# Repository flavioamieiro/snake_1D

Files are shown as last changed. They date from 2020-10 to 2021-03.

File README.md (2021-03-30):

A snake trapped in one dimension.

It's always there, but you'll need a strip of ws2812b LEDs to see and interact with it.

Here, you'll find two species: The [python](fadecandy_python/#readme),
for which you'll need a computer and a
[fadecandy](https://github.com/scanlime/fadecandy) and the
[tiny](attiny85_arduino_IDE/#readme), for which you can use the
standalone [hardware](hardware/#readme).

The software in this repository is licensed under the GPLv3 and the hardware
under the CERN-OHL-S v2.

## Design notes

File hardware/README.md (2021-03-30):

Kicad project with schematics and PCB design for the 1D Snake Game
running on an ATTiny85.

This source describes Open Hardware and is licensed under the
CERN-OHL-S v2.  You may redistribute and modify this source and make
products using it under the terms of the CERN-OHL-S v2
(https://ohwr.org/cern_ohl_s_v2.txt).

This source is distributed WITHOUT ANY EXPRESS OR IMPLIED WARRANTY,
INCLUDING OF MERCHANTABILITY, SATISFACTORY QUALITY AND FITNESS FOR A
PARTICULAR PURPOSE. Please see the CERN-OHL-S v2 for applicable
conditions.

Source location:
https://github.com/flavioamieiro/snake_1D

As per CERN-OHL-S v2 section 4, should You produce hardware based on
this source, You must where practicable maintain the Source Location
visible on the external case of the Gizmo or other products you make
using this source.

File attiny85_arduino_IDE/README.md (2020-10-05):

Code to run the 1D Snake Game in an ATtiny85 microcrontroler.

It was written in the arduino IDE using
[ATTinyCore](https://github.com/SpenceKonde/ATTinyCore). Please refer
to [their
documentation](https://github.com/SpenceKonde/ATTinyCore#readme) for
installation/programming instructions.

You can refer to the [hardware design files](../hardware/) to see what
you need to hookup to the microcrontroler. If you only want to test it
out, you might get away with only 5V between `Vcc` and `GND`, the
pushbutton on `PB4` and the LED strip's `Din` on `PB3`, but please be
aware that I didn't implement any debouncing in software, so the
button might be very bouncy.

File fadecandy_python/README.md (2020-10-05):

This is a python implementation of the 1D Snake Game using
[fadecandy](https://github.com/scanlime/fadecandy) to control the LED
strip.

The code is basically copied over from [an earlier
implementation](https://github.com/flavioamieiro/snake_game/) and
adapted to use an LED strip for output.

I recommend creating a [virtual
environment](https://docs.python.org/3/tutorial/venv.html) and
installing the requirements with `pip install -r
requirements.txt`. This code was written using python 3.8.2.

Then you need the fadecandy server running on your computer and hook
it up as described in the simple example in [fadecandy's
documentation simple example](https://github.com/scanlime/fadecandy/blob/master/README.md#simple-example):

Fadecandy system diagram 1

After that, just run `python snake_game.py`. The space bar controls the snake.

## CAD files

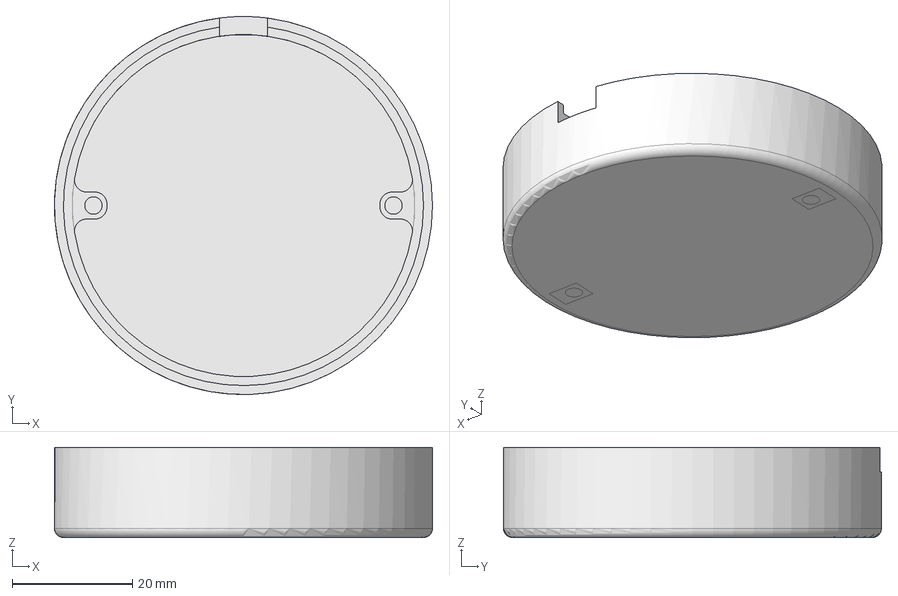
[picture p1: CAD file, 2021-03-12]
hardware/Enclosure/Snake_1d.FCStd
63.0 x 63.0 x 15.0 mm

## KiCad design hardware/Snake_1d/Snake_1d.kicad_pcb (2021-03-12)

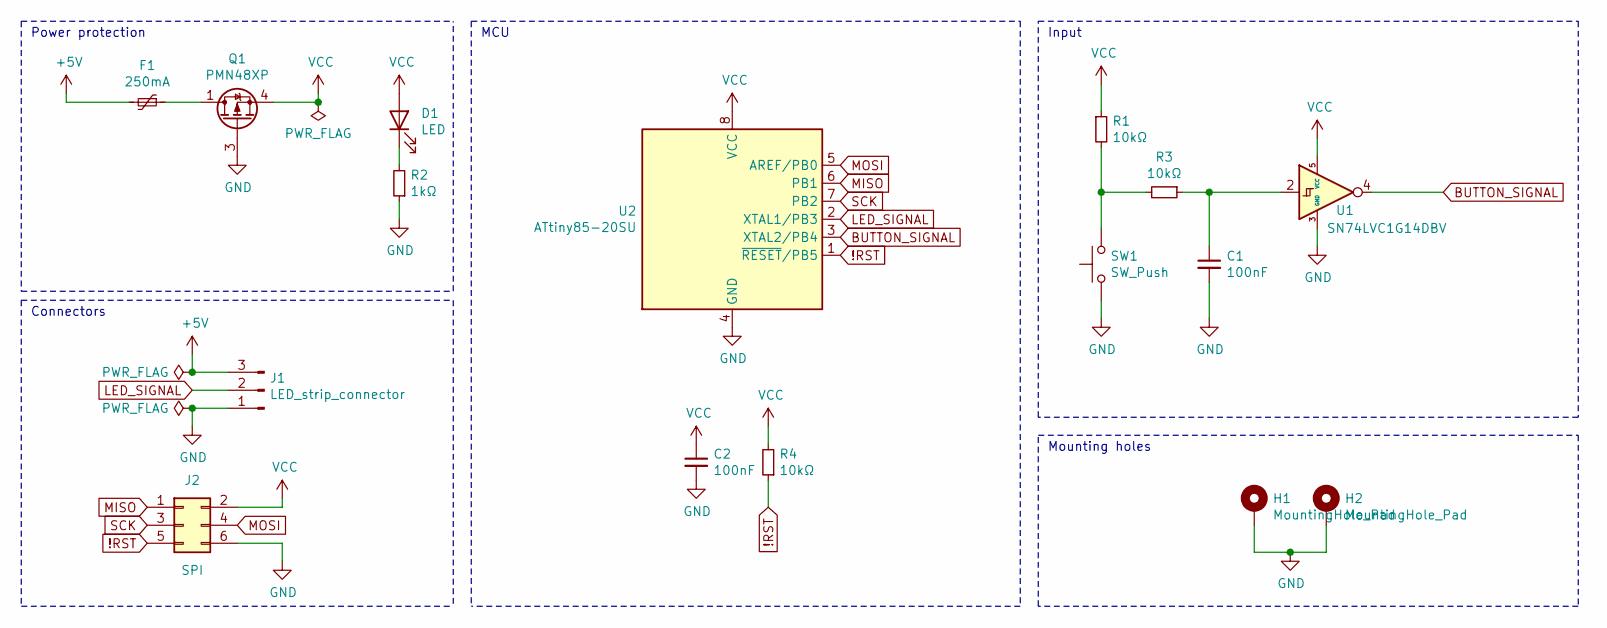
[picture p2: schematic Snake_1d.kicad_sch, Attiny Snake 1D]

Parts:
C1, C2: 100nF; C_1206_3216Metric_Pad1.33x1.80mm_HandSolder
D1: LED; LED_1206_3216Metric_Pad1.42x1.75mm_HandSolder
F1: 250mA; Fuse_1206_3216Metric_Pad1.42x1.75mm_HandSolder
H1, H2: MountingHole_Pad; MountingHole_3.2mm_M3_Pad_Via
J1: LED_strip_connector; PinHeader_1x03_P2.54mm_Horizontal
J2: SPI; SPI_pads_2.54mm
Q1: PMN48XP; TSOP-6_1.65x3.05mm_P0.95mm
R1, R3, R4: 10kΩ; R_0805_2012Metric_Pad1.20x1.40mm_HandSolder
R2: 1kΩ; R_1206_3216Metric_Pad1.30x1.75mm_HandSolder
SW1: SW_Push; SW_Cherry_MX_1.00u_PCB
U1: SN74LVC1G14DBV; SOT-23-5_HandSoldering
U2: ATtiny85-20SU; SOIJ-8_5.3x5.3mm_P1.27mm

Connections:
!RST: J2.5, R4.1, U2.1 (~RESET~/PB5)
+5V: F1.2, J1.3
BUTTON_SIGNAL: U1.4, U2.3 (XTAL2/PB4)
GND: C1.2, C2.2, H1.1, H2.1, J1.1, J2.6, Q1.3 (G), R2.1, SW1.1, U1.3 (GND), U2.4 (GND)
LED_SIGNAL: J1.2, U2.2 (XTAL1/PB3)
MISO: J2.1, U2.6 (PB1)
MOSI: J2.4, U2.5 (AREF/PB0)
unnamed: C1.1, R3.1, U1.2
unnamed: D1.1 (K), R2.2
unnamed: F1.1, Q1.1 (D), Q1.2 (D), Q1.5 (D), Q1.6 (D)
unnamed: R1.2, R3.2, SW1.2
SCK: J2.3, U2.7 (PB2)
VCC: C2.1, D1.2 (A), J2.2, Q1.4 (S), R1.1, R4.2, U1.5 (VCC), U2.8 (VCC)

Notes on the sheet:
Power protection
Connectors
MCU
Input
Mounting holes

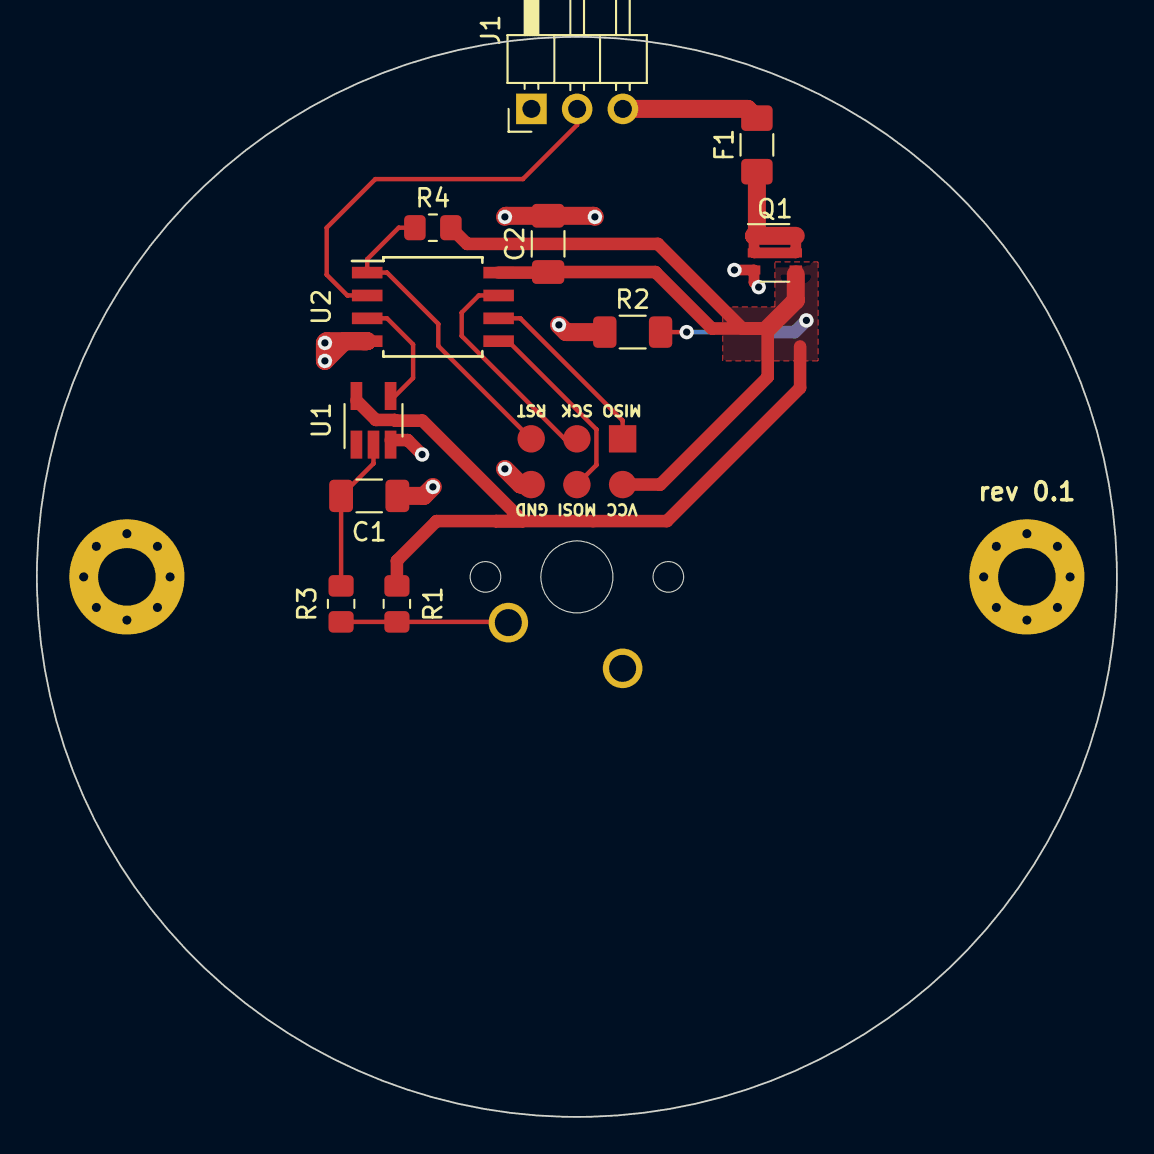
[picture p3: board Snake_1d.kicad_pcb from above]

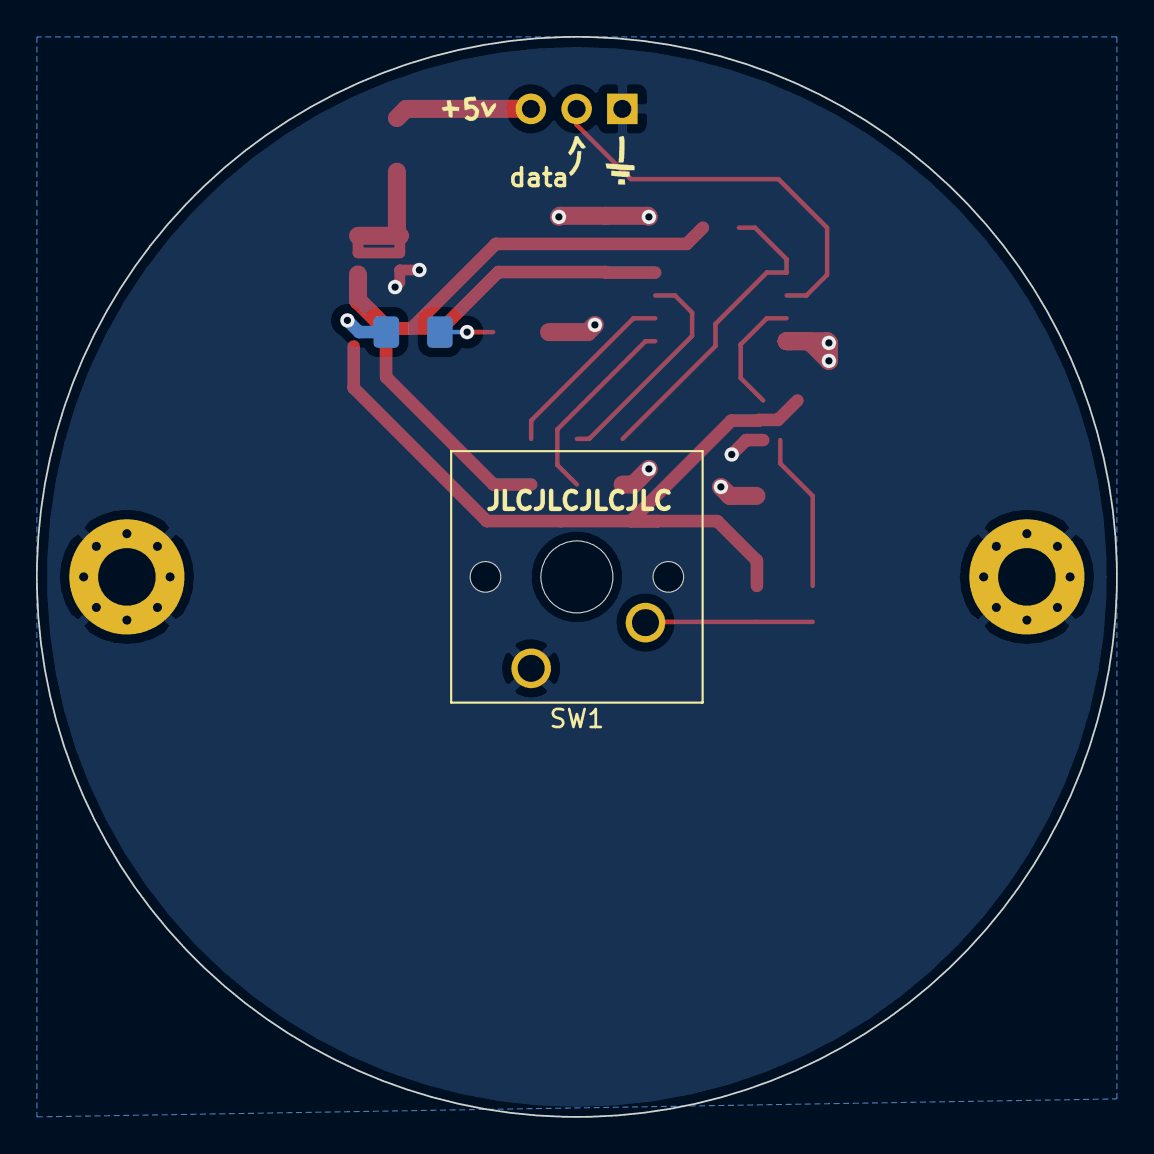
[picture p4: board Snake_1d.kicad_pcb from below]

Board: 2 copper layers, 60.0 x 60.0 mm, 19 parts (5 on the bottom side), 13 nets.

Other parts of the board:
Ref**: Val**; 5v_FSilks
Ref**#2: Val**; arrow_up_from_left
Ref**#3: Val**; ground_FSilks

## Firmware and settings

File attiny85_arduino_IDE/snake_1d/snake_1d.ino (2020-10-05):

// 1D Snake Game running on an ATTiny85
// Copyright (C) 2020 Flávio Amieiro <amieiro.flavio@gmail.com>
//
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
#include <Adafruit_NeoPixel.h>
#include <avr/power.h>
#include <avr/io.h>
#include <avr/interrupt.h>

#define DEBUG false

#define DEBUG_PIN 1
#define BUTTON_PIN 4
#define LED_PIN 3
#define LED_COUNT 64

#define INITIAL_TIMEOUT 200
#define TIMEOUT_STEP 30
#define TIMEOUT_LIMIT 50

Adafruit_NeoPixel strip(LED_COUNT, LED_PIN, NEO_KHZ800 + NEO_GRB);

struct Snake {
  unsigned int pos;
  unsigned int len;
  int velocity;
  bool crashed;
  uint32_t color;
};

struct Fruit {
  unsigned int pos;
  uint32_t color;
};

struct Snake snake;

struct Fruit fruit;

unsigned int timeout;
int last_flip;
unsigned int level;

#if DEBUG
bool debug_state = true;
void debug() {
  debug_state = !debug_state;
  digitalWrite(DEBUG_PIN, debug_state);
}
#endif

ISR(PCINT0_vect) {
  if (digitalRead(BUTTON_PIN) == HIGH) {
    flip_snake();
    #if DEBUG
    debug();
    #endif
  }
}


static inline void initInterrupt(void)
{
  GIMSK |= (1 << PCIE);    // pin change interrupt enable
  PCMSK |= (1 << PCINT4 ); // pin change interrupt enabled for PCINT4
  sei();                   // enable interrupts
}


void setup() {
  clock_prescale_set(clock_div_1);

  pinMode(LED_PIN, OUTPUT);
  pinMode(BUTTON_PIN, INPUT_PULLUP);
  initInterrupt();
  reset();
  timeout = INITIAL_TIMEOUT;

  #if DEBUG
  pinMode(DEBUG_PIN, OUTPUT);
  digitalWrite(DEBUG_PIN, debug_state);
  #endif
}

void loop() {
  update_snake();
  draw();

  if (snake.crashed) {
    game_over();
  }
  if (level == 50) {
    won_game();
  }
  if (snake_hits_fruit()) {
    level_up();
  }

  delay(timeout);
}

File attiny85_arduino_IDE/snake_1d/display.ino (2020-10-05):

void solid_color(uint32_t color) {
    strip.clear();
    for(int i = 0; i < strip.numPixels(); i++) {
      strip.setPixelColor(i, color);
    }
    strip.show();
}

void end_animation(uint32_t color) {
  strip.clear();
  for(int i = 0; i < strip.numPixels(); i++) {
    strip.setPixelColor(i, color);
    strip.show();
  };
  strip.clear();
  strip.show();
  delay(100);
  solid_color(color);
  strip.show();
  delay(100);
  solid_color(color);
  strip.show();
  delay(100);
}

void draw_walls() {
  uint32_t wall_color = strip.Color(64, 64, 64);
  strip.setPixelColor(0, wall_color);
  strip.setPixelColor(LED_COUNT-1, wall_color);
}

void draw_fruit() {
  strip.setPixelColor(fruit.pos, fruit.color);
}

void draw_snake() {
  for (int i = 0; i < snake.len; i++) {
    if (snake.velocity > 0) {
      if (snake.pos - i > 0) {
        strip.setPixelColor(snake.pos - i, snake.color);
      }
    } else {
      if (snake.pos + i < LED_COUNT - 1) {
        strip.setPixelColor(snake.pos + i, snake.color);
      }
    }
  }
}

void draw() {
  strip.clear();
  draw_walls();
  draw_fruit();
  draw_snake();
  strip.show();
}

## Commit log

2020-10-05 Adds Fadecandy/Python implementation
    The code was basically copied from [an earlier
    implementation](https://github.com/flavioamieiro/snake_game) (minus
    tests) and adapted to use fadecandy to interface with the ws2812b LED
    strip.
2020-10-05 Adds ATTiny85 version of the game
    It's still buggy and doesn't run as smooth as the python version, but
    it runs without a computer and a USB connection.
    [display.ino, gameplay.ino, snake_1d.ino]
2020-10-05 Adds kicad project with hardware schematics
    It also includes the custom footprint for the programming port.
    [Snake_1d.sch]
2020-10-05 Adds courtyard area to SPI pads footprint
2020-10-05 Adds mounting holes to the schematic
    [Snake_1d.sch]
2020-10-06 Adds PCB layout
    The components are laid out and the tracks are routed, but I still need
    to improve the silkscreen and general look and feel.
    [Snake_1d.kicad_pcb]
2020-10-09 Moves LED via a bit away from the main Vcc rail
    [Snake_1d.kicad_pcb]
2020-10-09 Organizes silkscreen on the pcb
    [Snake_1d.kicad_pcb]
2020-10-09 Adds pcb file changes after generating Gerber files
    [Snake_1d.kicad_pcb]
2020-10-09 Adds revision number to silkscreen on pcb
    [Snake_1d.kicad_pcb]
2020-10-09 Adds pin 1 marks to ICs on the PCB
    [Snake_1d.kicad_pcb]
2020-10-09 Adds silkscreen labels to programming connector on PCB
    [Snake_1d.kicad_pcb]
2020-10-09 Adds JLC order number placeholder to pcb
    [Snake_1d.kicad_pcb]
2020-12-16 Moves connector label to the front side of the PCB
    [Snake_1d.kicad_pcb]
2020-12-16 Changes cherry switch to PCB mount
    [Snake_1d.kicad_pcb, Snake_1d.sch]
2020-12-16 Changes footprints to handsolder where possible
    [Snake_1d.kicad_pcb, Snake_1d.sch]
2020-12-16 Increases silk size for programming connector
    [Snake_1d.kicad_pcb]
2020-12-16 Fixes missing (silk) footprints
    [Snake_1d.kicad_pcb]
2021-02-10 Moves kicad files to new (nightly) format
    [Snake_1d.kicad_pcb, Snake_1d.kicad_sch, Snake_1d.sch]
2021-03-12 Changes LED strip connector footprint to horizontal pin header
    [Snake_1d.kicad_pcb, Snake_1d.kicad_sch]
2021-03-12 Adds Freecad project with the model of an enclosure for 3D printing
    [Snake_1d.FCStd]
2021-03-30 Updates kicad file version

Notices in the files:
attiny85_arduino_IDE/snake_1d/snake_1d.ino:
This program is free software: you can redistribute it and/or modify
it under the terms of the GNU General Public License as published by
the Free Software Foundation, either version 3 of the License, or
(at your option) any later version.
